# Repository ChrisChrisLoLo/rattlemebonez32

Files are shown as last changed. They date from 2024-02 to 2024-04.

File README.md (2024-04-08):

# rattlemebonez32

### A 32 key monoblock with minimal choc spacing and vibes

This pocket board is the bigger cousin to the [idawgz32](https://github.com/ChrisChrisLoLo/idawgz32). Same minimalist key layout, more egonomic form factor. Uses a CH552 as its MCU, and runs FAK firmware.

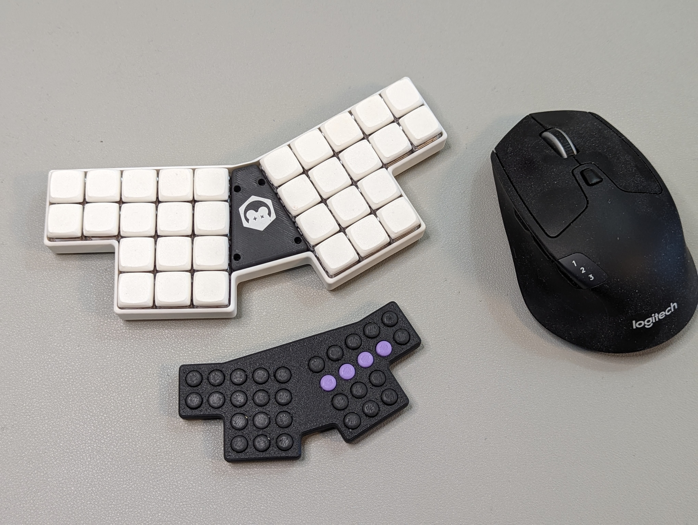
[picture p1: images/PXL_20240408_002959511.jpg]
a photo of a rattlemebonez32


# Status
PCBs include a choc variant and a ks33 variant. Both work, though I highly recommend the choc variant as it's much easier to
assmble (ks33 switches do not snap into the board, making soldering difficult but possible).

The keys on this board are minimally spaced (15mm x 15mm), and as such will need special keycaps. 

This repo has a minimally spaced choc keycap based on the Philidelphia minimalist. You will likely need a 3D printer such as a Bambu Lab A1/A1 mini/P1P/P1S and set the slicing layer resolution to 0.08mm for best results. Printers like the Prusa i3/mini may also work, but have not been tested.

# Case
The case files can be found in the `case` directory.

The case comes in two parts, the top section and the bottom section.

## PCB
You can find the PCB source files in the `pcb` folder. The BOM files can be found in this folder.

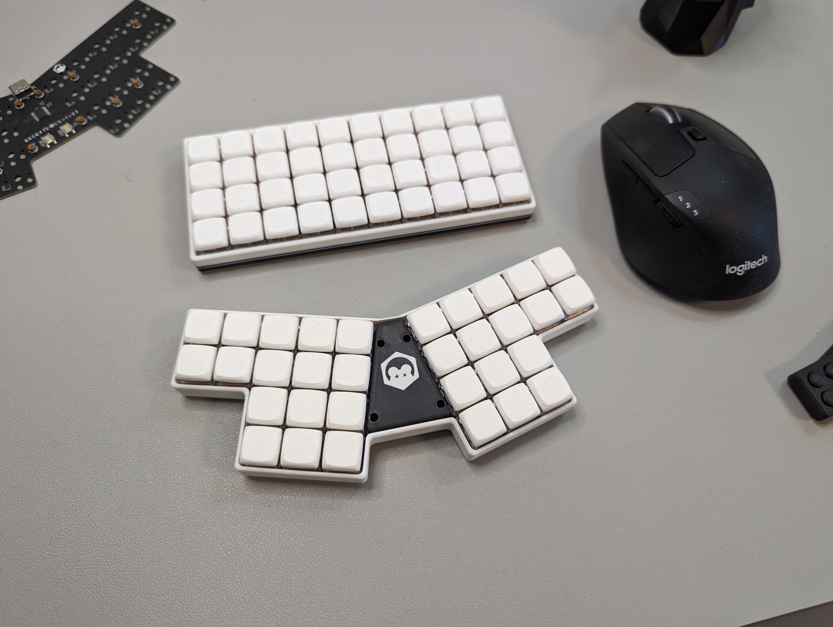
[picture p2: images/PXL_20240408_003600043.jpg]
rattlemebonez pcb


## Directory Structure
- `case`
    You can find the files you need in this folder to print out a case and choc switches for the keyboard
- `drafts`
    Stores any ergogen or intermediate information used in making the case
- `pcb`
    Kicad project relating to the project. Contains the BOM, placement files, and gerbers
   
## BOM
- 1 PCBA
  - The PCB will include all electrical parts required, including switches.
- 1 Aluminum CNC upper case or 3DP upper case (technically optional, but strongly recommended)
- 1 Alumminum CNC lower case or CNC lower case
- 12 3mm M1.6 screws (go for flathead for a more flush fit, though other head types should also work)
- 8 1-2mm bumpons (something like Sj5302 is a good place to start)

## Assembly
Flash the pcb with my FAK branch (see below section). Bootmagic is enabled, so using the top left key to flash from here on out is doable.

Pop the 3D printed buttons/keycaps into the case. and screw the bottom case to the PCBA. Then place on the top and screw the top case to the PCBA.

Finally, place on the rubber bumpons

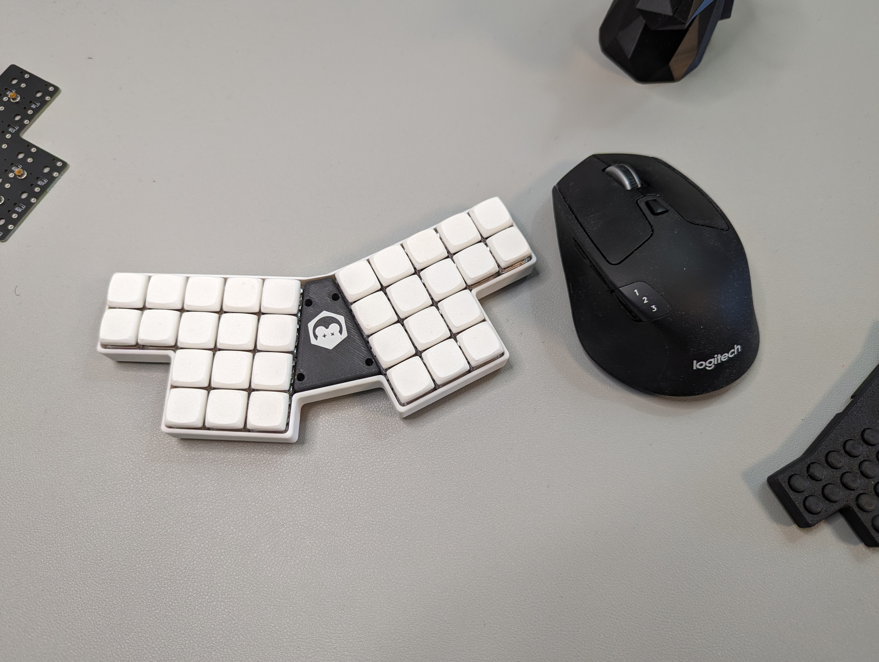
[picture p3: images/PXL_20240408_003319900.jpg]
rattlemebonez assembly


## Firmware
Branch and fork of FAK Firmware can be found here:
https://github.com/ChrisChrisLoLo/fak/tree/rattlemebonez32

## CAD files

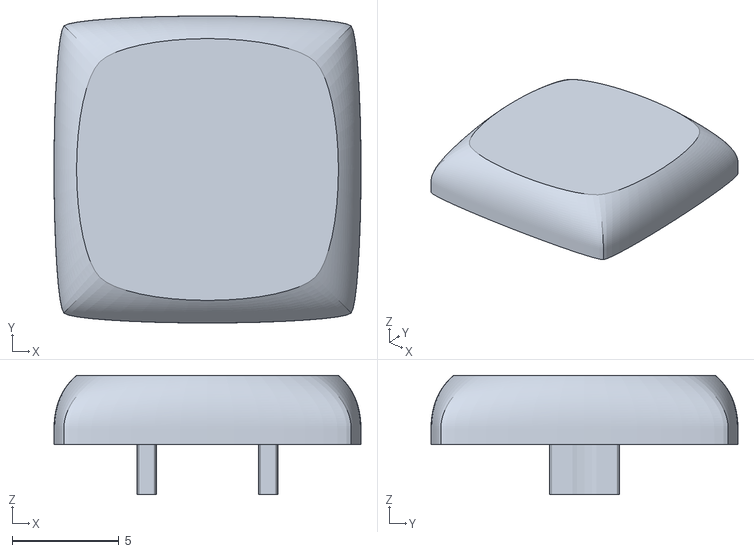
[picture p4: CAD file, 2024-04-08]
case/keycaps/choc/Philadelphia_Minimalist_Custom_PLA.stl
14.4 x 14.4 x 5.60

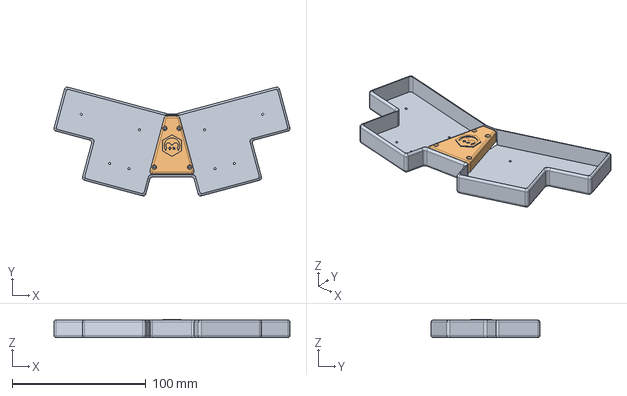
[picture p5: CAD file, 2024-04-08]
case/rattlemebonez32 v7.step
176.3 x 81.4 x 13.6 mm

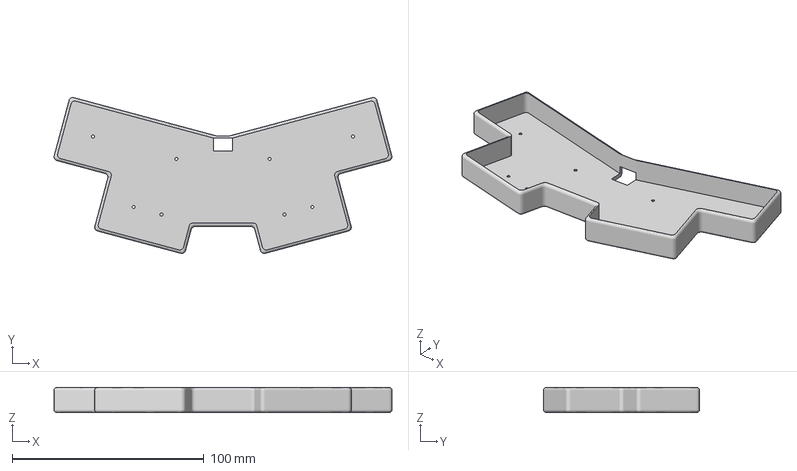
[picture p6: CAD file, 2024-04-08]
case/case_bottom.3mf
176.3 x 81.4 x 13.1 mm

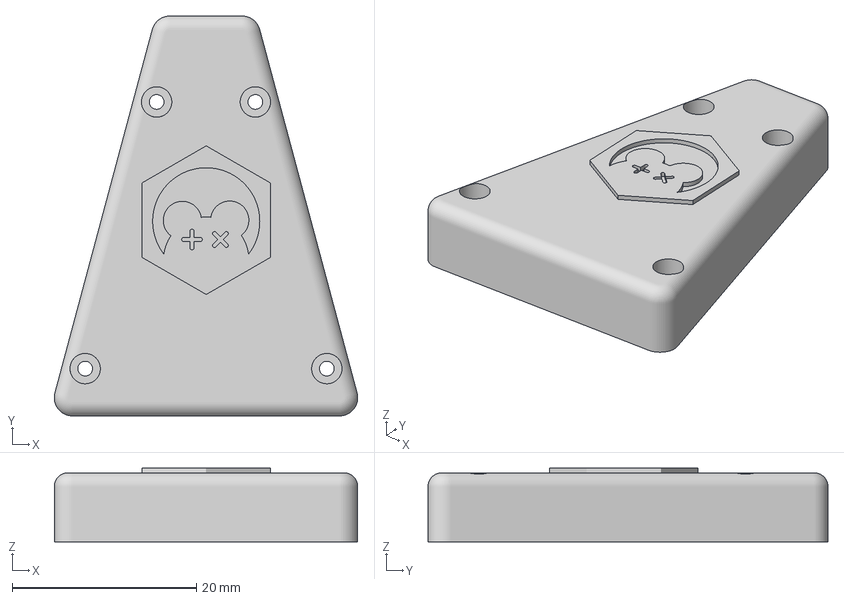
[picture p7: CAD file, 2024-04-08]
case/case_top.3mf
33.0 x 43.5 x 8.00 mm

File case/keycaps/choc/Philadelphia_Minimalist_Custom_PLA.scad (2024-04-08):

use <scad-utils/morphology.scad> //for cheaper minwoski 
use <scad-utils/transformations.scad>
use <scad-utils/shapes.scad>
use <scad-utils/trajectory.scad>
use <scad-utils/trajectory_path.scad>
use <sweep.scad>
use <skin.scad>  
use <z-butt.scad>
//TODOs 
//add shell towards bottom to make it rounder
//add o-ring portion 
//add variable radius for outer fillet
//Fanning? for thumbs
//MX stem


//enum 
Choc = 0;
MX = 1;
Null =2;
// override Z-butt param 
lp_key = [
//     "base_sx", 18.5,
//     "base_sy", 18.5,
     "base_sx", 17.65,
     "base_sy", 16.5,
     "cavity_sx", 16.1,
     "cavity_sy", 14.9,
     "cavity_sz", 1.6,
     "cavity_ch_xy", 1.6,
     "indent_inset", 1.5
     ];
/*Tester */
//translate([0,0,0])lp_master_base(xu = 2, yu = 1 );  

translate([0, 0, -.05])rotate([0,0,0])mirror([0,1,0]){
//  keycap(keyID = 6, cutLen = 0, Stem = Choc,  Dish = false, SecondaryDish = false, visualizeDish = false, crossSection = false, homeDot = false, Legends = false);
}
translate([0, 0, 0])rotate([0,0,0])mirror([0,0,0]){
  keycap(keyID = 0, cutLen = 0, Stem = Choc,  Dish = false, SecondaryDish = false, visualizeDish = false, crossSection = false, homeDot = false, Legends = false);
}

// translate([14, 14, 0])rotate([0,0,90]) keycap(keyID = 0, cutLen = 0, Stem =true,  Dish = true, SecondaryDish = false,Stab = 0 , visualizeDish = false, crossSection = false, homeDot = false, Legends = false);
// translate([0, 14, 0])rotate([0,0,90]) keycap(keyID = 0, cutLen = 0, Stem =true,  Dish = true, SecondaryDish = false,Stab = 0 , visualizeDish = false, crossSection = false, homeDot = false, Legends = false);
// translate([14, 0, 0])rotate([0,0,90]) keycap(keyID = 0, cutLen = 0, Stem =true,  Dish = true, SecondaryDish = false,Stab = 0 , visualizeDish = false, crossSection = false, homeDot = false, Legends = false);

//translate([-18, 0, 10])rotate([0,0,90])mirror([0,0,0])keycap(keyID = 2, cutLen = 0, Stem =true,  Dish = false, SecondaryDish = false,Stab = 0 , visualizeDish = false, crossSection = false, homeDot = false, Legends = false);

//#translate([0,0,0])cube([14, 14, 2], center = true); // internal check
//#translate([1,0,0])cube([12, 14, 4], center = true); // internal check
//#translate([2,0,0])cube([11, 14, 4], center = true); // internal check
//#translate([0,0,5])cube([19.05, 19.05, 10], center = true); // internal check
//#translate([0,0,0])cube([17.5, 16.5, 10], center = true); // internal check
ChocCut = 0;

thumbStem = true;
thumbDish = true;
thumbVis  = false;
thumbSec  = false;


//-Parameters
wallthickness = 1.1; // 1.75 for mx size, 1.1
topthickness = 2.5; //2 for phat 3 for chicago
stepsize = 60;  //resolution of Trajectory
step =2;       //resolution of ellipes 
fn = 16;          //resolution of Rounded Rectangles: 60 for output
layers = 20;    //resolution of vertical Sweep: 50 for output
angularSteps = 20;

//---Stem param

//injection param
draftAngle = 0; //degree  note:Stem Only
Tol    = 0.10; //stem tolarance
stemRot = 0;
stemRad = 5.55; // stem outer radius
stemLen = 5.55 ;
stemCrossHeight = 4;
extra_vertical  = 0.6;
StemBrimDep     = 0.25; 
stemLayers      = 50; //resolution of stem to cap top transition
//TODO: Add wall thickness transition?


keyParameters = //keyParameters[KeyID][ParameterID]
[ 
//  BotWid, BotLen, TWDif, TLDif, keyh, WSft, LSft  XSkew, YSkew, ZSkew,/*|*/ WEx, LEx, CapR0i, CapR0f, CapR1i, CapR1f, CapREx, StemEx, chop shift
    //Column 0    
    //set R2 14x14 choc trantisiton  
    [13.50,  13.50, 3.0, 3.0,  2.5,  0.0,  0.0, 0.0, -0, -0,/*|*/ 2,   2,    1,      3,     1,      3,     2,       2, 0], //R2 Top surface  
    [12.40,  12.40, 5.0, 8.0,-0.75,  0.0,  0.0, 0.0, -0, -0,/*|*/ 1,   1,    2,      3,     2,      3,     2,       2, 0], //R2 Bottom Choc surface 
    [12.40,  12.40, 5.0, 8.0,-0.75,  0.0,  0.0, 0.0, -0, -0,/*|*/ 1,   1,    2,      3,     2,      3,     2,       2, 0], //R2 Bottom MX  surface  
   //MX chop
    [12.40,  10.40, 3.0, 3.0,  2.5,  0.0,  0.0, 0.0, -0, -0,/*|*/ 2,   2,    2,      3,     2,      3,     2,       2, -1], //R3 Chop Top surface  
    [12.40,  10.40, 5.0, 6.0,-0.75,  0.0, -1.0, 0.0, -0, -0,/*|*/ .5,  1.2,  2,      1,     2,      1,     2,       2, -1], //R3 Chop Bottom surface  
    [12.40,  10.40, 12.40-5.5, 10.40-5.5,-0.5,  0.0, -1.0, 0.0, -0, -0,/*|*/ 1, 1, 2, 5.5,    2,  5.5,     2,       2, -1], //R3 MX Bottom surface  
//Choc Chop
    [12.40,  9.40, 3.0, 3.0,  2.5,  0.0,  0.0, 0.0, -0, -0,/*|*/ 2,   2,    2,      3,     2,      3,     2,       2, -2], //R3 Chop Top surface  
    [12.40,  9.40, 5.0, 6.0,-0.75,  0.0, -2.0, 0.0, -0, -0,/*|*/ 2,   2,  2,      1,     2,      1,     2,       2, -2], //R3 Chop Bottom surface  
    [12.40,  9.40, 12.40-5.5, 10.40-5.5,-0.5,  0.0, -1.0, 0.0, -0, -0,/*|*/ 1,  1,  2,  5.5, 2,  5.5,     2,       2, -1], //R3 MX Bottom surface  
    
    [17.20,  16.00, 5.6, 5.0,  4.6,    0,   .0,   0, -0, -0, 2, 2.5,  .10,      3,   .10,      3,     2,       2, 0], //R3 bottom
    //Thumb
    [17.20,  16.00,  4.25, 	3.25,  5.0,  -.5,  0.0,    -3,    -3,    -0,   2,   2,    .10,      2,     .10,      2,     2,       2], //Thumb 1
    [15.65,  26.4,   5.5, 	3.25,  4.9,  -.5,  0.0,    -3,    -2,    -2,   2,   2,     .3,      2,      .3,    2.5,     2,       2], //Thumb 1.5
    [15.65,  35.8,  4.25, 	3.25,  4.9, -.25,  0.0,    -2.5,    -4,    -2,   2,   3,     .3,      2,      .3,    2.5,     2,       2], //Thumb 2.0
    //1.25 5

];

dishParameters = //dishParameter[keyID][ParameterID]
[ 
//FFwd1 FFwd2 FPit1 FPit2  DshDep DshHDif FArcIn FArcFn FArcEx     BFwd1 BFwd2 BPit1 BPit2  BArcIn BArcFn BArcEx FTani FTanf BTani BTanf TanEX PhiInit PhiFin phiEX
  //Column 0
  [   4, 4.5, 3, -50,  7,  1.7, 11,  17,   2, /*|*/ 4.5,  4,  2,  -35,   11,    15,     2,     2,  3,    2,  3,   2, 203, 198, 2], //full
  [ 4.5,   4, 5, -40,7,1.7,11,15,2,4.5,4,5,-40,11,15,2,4,5,4,5,2, 200, 210,2], //Chicago Steno R3 flat
  [ 4.5,    4,    5,  -40,      7,    1.7,   11,    15,     2,      4.5,    4,    5,   -40,   11,    15,     2,     4,    5,    4,    5,   2, 200, 210,2], //Chicago Steno R3 flat
  
  [3.5, 4.5,  3, -30,  7,  1.7, 11,  17,   2, /*|*/ 3.,  3,  2.2,  -60,   11,    15,     2,     2,  3,    2,  3,   2, 203, 194, 2], //Chop
  [ 4.5,4,5,-40,7,1.7,11,15,2,4.5,4,5,-40,11,15,2,4,5,4,5,2, 200, 210,2], //
  [ 4.5,4,5,-40,7,1.7,11,15,2,4.5,4,5,-40,11,15,2,4,5,4,5,2, 200, 210,2], //
  
  [ 4, 5.5,  6, -60,  7,  1.7, 11,  17,   2, /*|*/ 2.5,  2,  -6,  -180,   11,    17,     2,     2,  3,    2,  3,   2, 203, 194, 2], //Chop
  [ 4.5,4,5,-40,7,1.7,11,15,2,4.5,4,5,-40,11,15,2,4,5,4,5,2, 200, 210,2], //
  [ 4.5,4,5,-40,7,1.7,11,15,2,4.5,4,5,-40,11,15,2,4,5,4,5,2, 200, 210,2], //
//Chicago Steno R3 flat

  [   5,  5.5,    0,  -40,      7,    1.7,   16,    18,     2,       5.5,  3.5,    5,   -50,   16,    18,     2,     5,   3.75,    2,    3.75,   2, 199, 210], //T1
  [  10,  4.5,    0,  -40,      7,    1.7,   16,    15,     2,        10,  3.5,    5,   -50,   16,    18,     2,     3,   3.75,    .75,    3.75,   2, 200, 210], //1.5u 
  [  14.5, 4.5,   4,  -40,      7,    1.7,   16,    18,     2,      14.5,  4.5,    2,   -35,   16,    23,     2,     3,   3.75,    .75,    3.75,   2, 200, 210], //2.0u 
];

SecondaryDishParam = 
[  
  [   6,  3.5,    7,  -50,      3,    2,    8,     8,     2,          5,    5,    5,    15,   10,   20,     2], //Chicago Steno R2/R4
  [   6,  3.5,    7,  -50,      3,  2.5,    8,    20,     3,          2,  4.2,    8,     0,    8,    8,     3], //Chicago Steno R3 flat
  [   6,  3.5,    7,  -50,      3,  2.5,    8,    20,     3,          2,  4.2,    8,     0,    8,    8,     3], //Chicago Steno R3 chord
  
  [   6,  3.5,    7,  -50,      3,    2,    8,     8,     2,          5,    5,    5,    15,   10,    20,     2], //Levee Steno R2/R4
  [   6,  3.5,    7,  -50,      5,  1.0,   16,    23,     2,          6,  3.5,    7,   -50,   16,    23,     2], //Levee Steno R2/R4
  [   6,  3.5,    7,  -50,      5,  1.0,   16,    23,     2,          6,  3.5,    7,   -50,   16,    23,     2], //Levee Steno R2/R4

  [   6,  3.5,    7,  -50,      5,  1.0,   16,    23,     2,          6,  3.5,    7,   -50,   16,    23,     2], //Levee Steno R2/R4
  [   6,  3.5,    7,  -50,      5,  1.0,   16,    23,     2,          6,  3.5,    7,   -50,   16,    23,     2], //Levee Steno R2/R4
  [   6,  3.5,    7,  -50,      5,  1.0,   16,    23,     2,          6,  3.5,    7,   -50,   16,    23,     2], //Levee Steno R2/R4
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

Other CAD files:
case/rattlemebonez32 v7.f3d

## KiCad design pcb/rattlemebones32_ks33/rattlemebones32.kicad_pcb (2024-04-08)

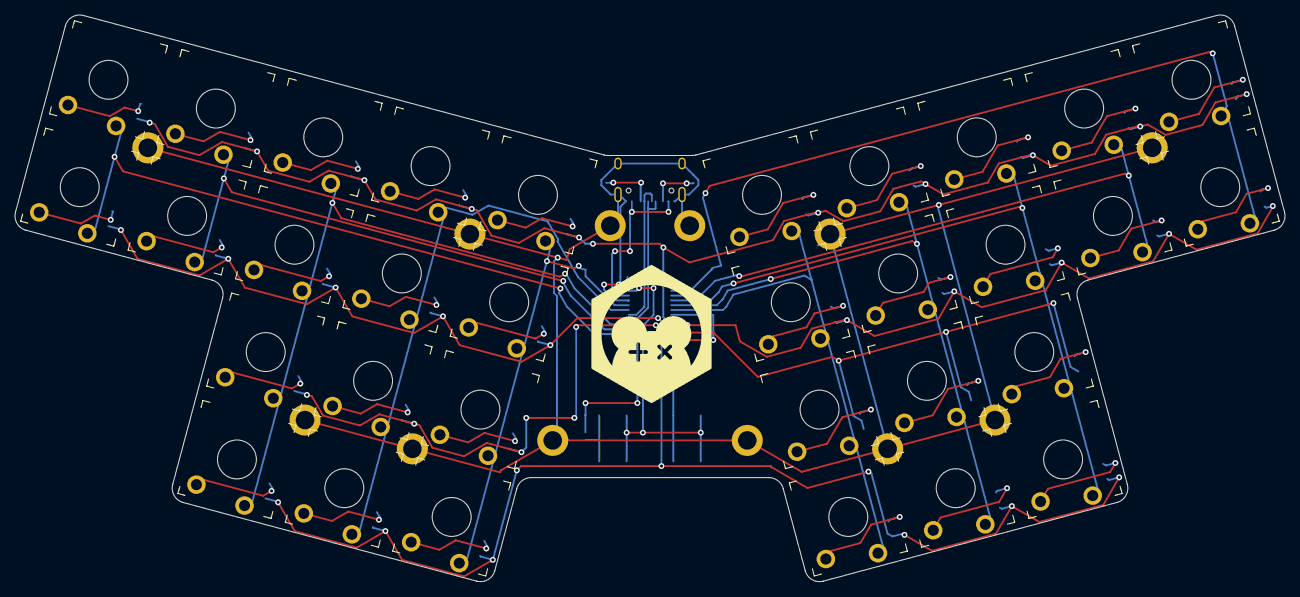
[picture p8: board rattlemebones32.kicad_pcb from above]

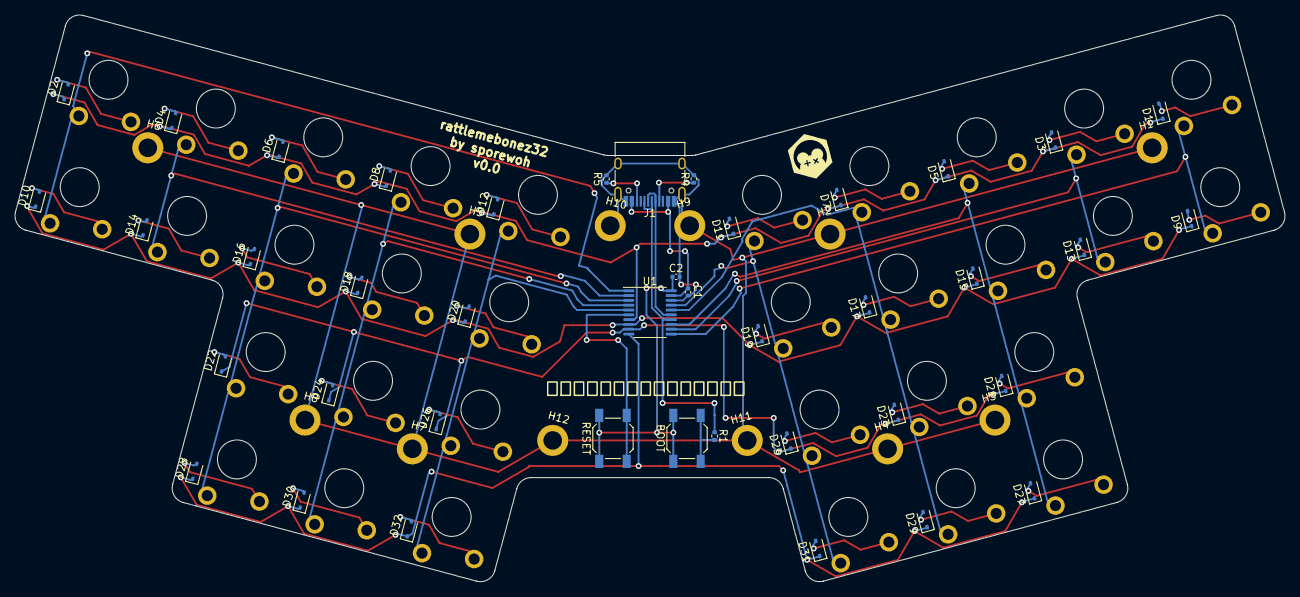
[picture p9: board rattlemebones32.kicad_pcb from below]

Board: 2 copper layers, 171.4 x 76.5 mm, 85 parts (53 on the bottom side), 55 nets.

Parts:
C1, C2: 100nF; C_0402_1005Metric
D1, D2, D3, D4, D5, D6, D7, D8, D9, D10, D11, D12, D13, D14, D15, D16, D17, D18, D19, D20, D21, D22, D23, D24, D25, D26, D27, D28, D29, D30, D31, D32: D_Small; D_SOD-323
H1, H2, H3, H4, H5, H6, H7, H8, H9, H10, H11, H12: MountingHole_Pad; SMTSO-M1.6
J1: USB_C_Receptacle_USB2.0; USB_C_Receptacle_HRO_TYPE-C-31-M-12
R1: 10k; R_0402_1005Metric
R4, R5: 5.1k; R_0402_1005Metric
SW1, SW2, SW3, SW4, SW5, SW6, SW7, SW8, SW9, SW10, SW11, SW12, SW13, SW14, SW15, SW16, SW17, SW18, SW19, SW20, SW21, SW22, SW23, SW24, SW25, SW26, SW27, SW28, SW29, SW30, SW31, SW32: SW_Push; SW_Gateron_LowProfile_THT
SW33: BOOT; SW_SPST_SKQG_WithStem
SW34: RESET; SW_SPST_SKQG_WithStem
U1: CH552T; TSSOP-20_4.4x6.5mm_P0.65mm

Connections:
+3.3V: C2.1, SW33.2, SW34.2, U1.20 (V33)
BOOT: R1.2, SW33.1
CC1: J1.A5 (CC1), R4.1
CC2: J1.B5 (CC2), R5.1
GND: C1.2, C2.2, H1.1, H2.1, H3.1, H4.1, H5.1, H6.1, H7.1, H8.1, H9.1, H10.1, H11.1, H12.1, J1.A1 (GND), J1.A12 (GND), J1.B1 (GND), J1.B12 (GND), J1.S1 (SHIELD), R4.2, R5.2, U1.18 (GND/VSS)
unnamed: D1.2 (A), SW1.1
unnamed: D2.2 (A), SW2.1
unnamed: D3.2 (A), SW3.1
unnamed: D4.2 (A), SW4.1
unnamed: D5.2 (A), SW5.1
unnamed: D6.2 (A), SW6.1
unnamed: D7.2 (A), SW7.1
unnamed: D8.2 (A), SW8.1
unnamed: D9.2 (A), SW9.1
unnamed: D10.2 (A), SW10.1
unnamed: D11.2 (A), SW11.1
unnamed: D12.2 (A), SW12.1
unnamed: D13.2 (A), SW13.1
unnamed: D14.2 (A), SW14.1
unnamed: D15.2 (A), SW15.1
unnamed: D16.2 (A), SW16.1
unnamed: D17.2 (A), SW17.1
unnamed: D18.2 (A), SW18.1
unnamed: D19.2 (A), SW19.1
unnamed: D20.2 (A), SW20.1
unnamed: D21.2 (A), SW21.1
unnamed: D22.2 (A), SW22.1
unnamed: D23.2 (A), SW23.1
unnamed: D24.2 (A), SW24.1
unnamed: D25.2 (A), SW25.1
unnamed: D26.2 (A), SW26.1
unnamed: D27.2 (A), SW27.1
unnamed: D28.2 (A), SW28.1
unnamed: D29.2 (A), SW29.1
unnamed: D30.2 (A), SW30.1
unnamed: D31.2 (A), SW31.1
unnamed: D32.2 (A), SW32.1
RST: SW34.1, U1.6 (RST/T2EX_/CAP2_)
UDM: J1.A7 (D-), J1.B7 (D-), U1.15 (P3.7/UDM)
UDP: J1.A6 (D+), J1.B6 (D+), R1.1, U1.14 (P3.6/UDP)
VBUS: C1.1, J1.A4 (VBUS), J1.A9 (VBUS), J1.B4 (VBUS), J1.B9 (VBUS), U1.19 (VCC/VDD)
col1: SW2.2, SW10.2, U1.1 (P3.2/TXD1_/INT0/VBUS1/AIN3)
col2: SW4.2, SW14.2, U1.2 (P1.4/T2_/CAP1_/SCS/TIN2/UCC1/AIN1)
col3: SW6.2, SW16.2, SW22.2, SW28.2, U1.3 (P1.5/MOSI/PWM1/TIN3/UCC2/AIN2)
col4: SW8.2, SW18.2, SW24.2, SW30.2, U1.4 (P1.6/MISO/RXD1/TIN4)
col5: SW12.2, SW20.2, SW26.2, SW32.2, U1.5 (P1.7/SCK/TXD1/TIN5)
col6: SW11.2, SW19.2, SW25.2, SW31.2, U1.17 (P1.2/XI/RXD_)
col7: SW7.2, SW17.2, SW23.2, SW29.2, U1.16 (P1.3/XO/TXD_)
col8: SW5.2, SW15.2, SW21.2, SW27.2, U1.13 (P3.5/T1)
col9: SW3.2, SW13.2, U1.12 (P3.4/PWM2/RXD1_/T0)
col10: SW1.2, SW9.2, U1.11 (P3.3/INT1)
row1: D1.1 (K), D2.1 (K), D3.1 (K), D4.1 (K), D5.1 (K), D6.1 (K), D7.1 (K), D8.1 (K), D11.1 (K), D12.1 (K), U1.7 (P1.0/T2/CAP1/TIN0)
row2: D9.1 (K), D10.1 (K), D13.1 (K), D14.1 (K), D15.1 (K), D16.1 (K), D17.1 (K), D18.1 (K), D19.1 (K), D20.1 (K), U1.8 (P1.1/T2EX/CAP2/TIN1/VBUS2/AIN0)
row3: D21.1 (K), D22.1 (K), D23.1 (K), D24.1 (K), D25.1 (K), D26.1 (K), U1.9 (P3.1/PWM2_/TXD)
row4: D27.1 (K), D28.1 (K), D29.1 (K), D30.1 (K), D31.1 (K), D32.1 (K), U1.10 (P3.0/PWM1_/RXD)

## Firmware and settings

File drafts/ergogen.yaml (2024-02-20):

  units:
    kx: 15
    ky: 15
    px: kx + 0
    py: ky + 0
    pp: 0.5px # pcb padding
    pm: pp+0.5 # pcb margin
    pw: pm+1.5 # case walls
    kcr: kx/2 + 0.6 # key cap radius
    kchr: kcr + 0.12 # key cap hole radius
    kcbr: kchr + 0.4 # key cap base radius
    kcbhr: kcbr + 0.12 # key cap base hole radius
    kcsx: kcbr * 2 # key cap slider x
    kcsy: 2.5 # key cap slider y
    kcsry: kcsy + 0.4 # key cap slider rail y
  points:
    zones:
      matrix:
        key:
          padding: 1px
          spread: 1px
        columns:
          pinky:
            rows.bottom.skip: true
            rows.mod.skip: true
          ring:
            rows.bottom.skip: true
            rows.mod.skip: true
          middle:
            key:
              stagger: 0 #ky/2
          index:
            key:
              stagger: 0 #5
          inner:
            key:
              stagger: 0 #5
        rows:
          mod:
          bottom:
          home:
          top:
    rotate: -15
    mirror:
      ref: matrix_inner_home
      distance: 38
  outlines:
    raw:
      - what: rectangle
        where: true
        size: [kx, ky]
        corner: 2
    keys:
      - what: rectangle
        where: true
        size: [kx-0.5,ky-0.5] # minus 0.5 just so we don't clip the pcb
        corner: 2
    key_holes:
      - what: rectangle
        where: true
        size: [kx, ky]
        corner: 2
    keycaps_top:
      - what: circle
        where: true
        radius: kcr
    keycaps_bottom:
      - what: circle
        where: true
        radius: kcbr
    keycaps_slider:
      - what: rectangle
        where: true
        size: [kcsx,kcsy]
        corner: 0.5
    keycaps_base_hole:
      - what: circle
        where: true
        radius: kcbhr
    keycaps_base_hole_rail:
      - what: rectangle
        where: true
        size: [kcbhr*2, kcsry]
        corner: 0.5
    key_rails_combo:
      - name: keycaps_base_hole_rail
      - operation: add
        name: key_holes
    pole_mounts_holes:
      - what: circle
        where: /(matrix_(pinky|index)_(top|bottom)|matrix_middle_bottom)/
        adjust.shift: [(px/2),-py/2]
        radius: 0.8 # screws are M2, but holes should be smaller
    pole_mounts:
      - what: circle
        where: /(matrix_(pinky|index)_(top|bottom)|matrix_middle_bottom)/
        adjust.shift: [(px/2),-py/2]
        radius: 2
      - operation: subtract
        name: pole_mounts_holes
    center_pole_mounts_holes:
      - what: circle
        where: /(matrix_inner_top|matrix_inner_bottom)/
        adjust.shift: [(px/2)+3,(-py/2)+6]
        radius: 0.8 # screws are M2, but holes should be smaller
    center_pole_mounts:
      - what: circle
        where: /(matrix_inner_top|matrix_inner_bottom)/
        adjust.shift: [(px/2)+3,(-py/2)+6]
        radius: 2
      - operation: subtract
        name: center_pole_mounts_holes
    board:
      - what: polygon
        operation: stack
        points:
          - ref: matrix_pinky_top
            shift: [-pp,pp]
          - ref: matrix_inner_top
            shift: [pp,pp]
          - ref: mirror_matrix_inner_top
            shift: [pp,pp]
          - ref: mirror_matrix_pinky_top
            shift: [-pp,pp]
          - ref: mirror_matrix_pinky_home
            shift: [-pp,-pp]
          - ref: mirror_matrix_middle_home
            shift: [-pp,-pp]
          - ref: mirror_matrix_middle_mod
            shift: [-pp,-pp]
          - ref: mirror_matrix_inner_mod
            shift: [pp,-pp]
          - ref: mirror_matrix_inner_bottom
            shift: [pp,-pp]
          - ref: matrix_inner_bottom
            shift: [pp,-pp]
          - ref: matrix_inner_mod
            shift: [pp,-pp]
          - ref: matrix_middle_mod
            shift: [-pp,-pp]
          - ref: matrix_middle_home
            shift: [-pp,-pp]
          - ref: matrix_pinky_home
            shift: [-pp,-pp]
        fillet: 2
    board_margin:
      - what: polygon
        operation: stack
        points:
          - ref: matrix_pinky_top
            shift: [-pm,pm]
          - ref: matrix_inner_top
            shift: [pm,pm]
          - ref: mirror_matrix_inner_top
            shift: [pm,pm]
          - ref: mirror_matrix_pinky_top
            shift: [-pm,pm]
          - ref: mirror_matrix_pinky_home
            shift: [-pm,-pm]
          - ref: mirror_matrix_middle_home
            shift: [-pm,-pm]
          - ref: mirror_matrix_middle_mod
            shift: [-pm,-pm]
          - ref: mirror_matrix_inner_mod
            shift: [pm,-pm]
          - ref: mirror_matrix_inner_bottom
            shift: [pm, -pm]
          - ref: matrix_inner_bottom
            shift: [pm, -pm]
          - ref: matrix_inner_mod
            shift: [pm,-pm]
          - ref: matrix_middle_mod
            shift: [-pm,-pm]
          - ref: matrix_middle_home
            shift: [-pm,-pm]
          - ref: matrix_pinky_home
            shift: [-pm,-pm]
        fillet: 2
    board_walls:
      - what: polygon
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

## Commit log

2024-02-20 pcb init
    [rattlemebones32.kicad_pcb, rattlemebones32.kicad_sch]
2024-04-08 exports and case init
    [case_bottom.3mf, case_top.3mf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]
2024-04-08 init keycaps
    [Philadelphia_Minimalist_Custom_PLA.scad, Philadelphia_Minimalist_Custom_PLA.stl]
2024-04-08 rename ks33 variant folder
    [rattlemebones32-B_Cu.gbr, rattlemebones32-B_Mask.gbr, rattlemebones32-B_Paste.gbr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]
